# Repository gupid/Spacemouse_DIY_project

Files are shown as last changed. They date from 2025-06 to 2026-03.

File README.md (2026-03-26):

# Spacemouse DIY Project

这是一个开源的 DIY 3D 鼠标 (Spacemouse) 工程。它基于沁恒(WCH)的 CH585 系列微控制器，旨在为 3D 设计、建模和工程人员提供一个高性价比的 3D 控制器解决方案。该设备集成了 3D 鼠标、普通鼠标和键盘功能，并支持有线、蓝牙(BLE)和私有 2.4G RF 连接。

## 硬件概述与驱动

主控为CH585，接收器为CH582F，键盘扫描芯片为CH450，均为沁恒产品。陀螺仪使用MPU9250。

接收器的电路设计借鉴了开源工程[CH582F接收器 - 立创开源硬件平台](https://oshwhub.com/bakacai/ch582f-jie-shou-qi)

主板和键盘PCB为自己设计。

驱动版本：[3Dconnexion 10.7.1](https://3dconnexion.com/cn/driver-download/)

## 主要功能

* **六轴自由度控制**: 使用 MPU9250 传感器，实现平移、旋转、缩放等直观的 3D 空间操作。
* **多模式切换**: 支持USB、BLE、2.4GHz三种模式连接
* **可编程按键**: 可在USB/2.4GHz模式下通过上位机自由修改。

## 演示视频

**[点击播放演示视频](./docs/media/spacemouse-demo.mp4)**

仅展示了外观与核心功能

## 工程文件结构

* **`Spacemouse_develop/`**: 这是 3D 鼠标设备本身的主体固件。
  * `APP/`: 应用层代码，包括主逻辑 `main.c` 和模式管理 `mode_manager.c` 等。
  * `Driver/`: 驱动程序，用于控制 MPU9250 传感器、CH450 按键芯片和 WS2812B RGB LED。
  * `Middleware/`: 中间件代码，处理运动数据、HID 报告和无线通信。
  * `HAL/`, `LIB/`, `StdPeriphDriver/`: 硬件抽象层、库文件和沁恒官方提供的标准外设驱动。
* **`spacemouse_RF_To_USB/`**: 这是CH585版本的 2.4G RF 无线接收器（USB Dongle）的固件。
  * `src/`: 接收器的主逻辑，负责接收 2.4G 信号并将其转换为 USB HID 数据。
  * `HAL/`, `LIB/`, `StdPeriphDriver/`: 与设备端类似的底层驱动和库。
* **`spacemouse_RF_To_USB_CH582/`**: 这是CH582版本的 2.4G RF 无线接收器（USB Dongle）的固件。
* `上位机`：这是和设备配套使用的，可以通过此HTML文件自由配置键值和转轴灵敏度。

## 写在最后

此工程为2025年嵌入式芯片与系统设计竞赛应用赛道——沁恒赛道的作品。实际上，到本次大赛结束时，我们的作品依然没有做完。这份决赛的代码，目前实现的功能有：USB模式、2.4GHz模式、上位机配置、比较稳定的陀螺仪控制。而仍然有待提升的有BLE模式，BLE模式极其不稳定，键盘和摇杆都有很大问题。

同时主板PCB设计也存在一定问题，锂电池的充电功能可行，但供电时却电压不足。

这个作品仍未走到它的结局，而我们和它和比赛的缘分却已走到尽头。

如果有缘，或许未来还会继续优化，我能感到，自己心中还有很多idea在熊熊燃烧。也欢迎所有朋友，如果你也对此感兴趣，希望这份工程能帮到你。

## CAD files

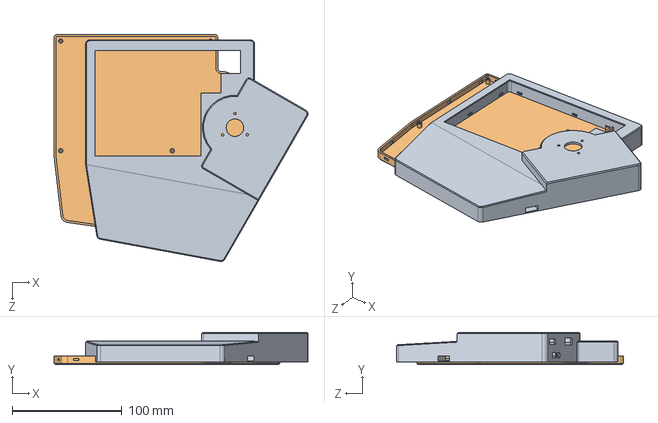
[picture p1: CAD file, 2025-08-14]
model/键盘壳V5.SLDASM
231.9 x 29.5 x 207.3 mm
键盘壳-底部V5
键盘壳-顶部V5

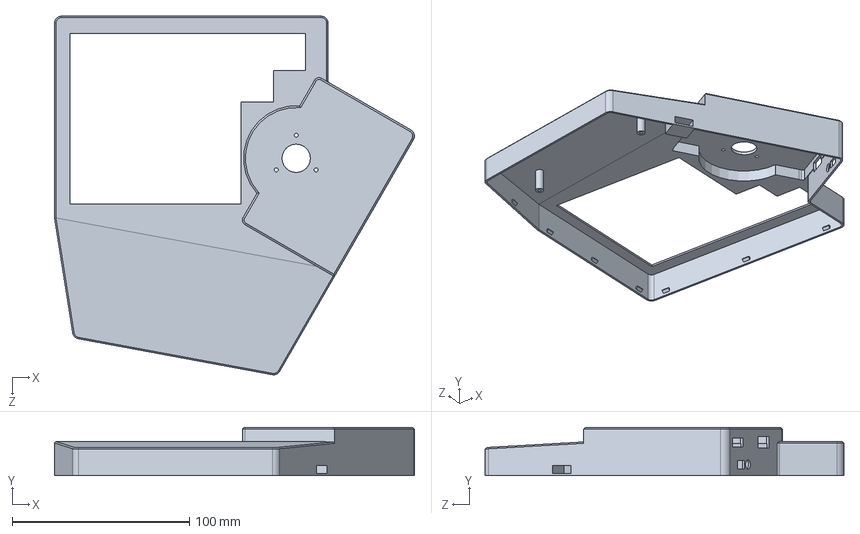
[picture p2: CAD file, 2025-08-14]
model/键盘壳-顶部V5.SLDPRT
203.1 x 27.2 x 202.4 mm

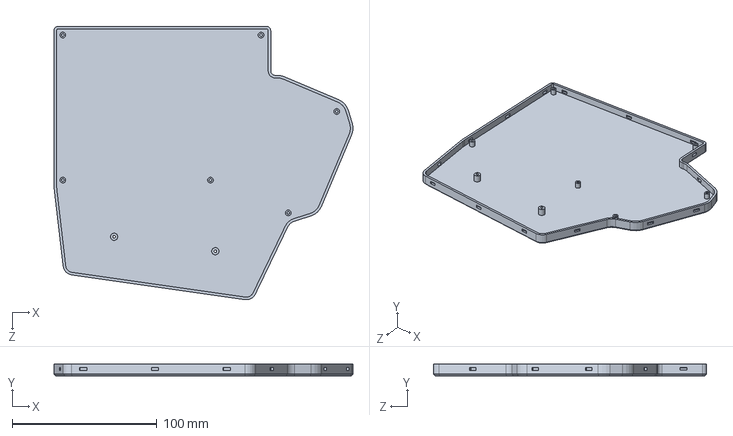
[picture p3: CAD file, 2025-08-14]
model/键盘壳-底部V5.SLDPRT
206.4 x 8.00 x 188.7 mm

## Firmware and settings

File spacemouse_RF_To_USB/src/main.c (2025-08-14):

// 文件名: main.c (环形缓冲区最终方案 - 完整无省略)
// 描述: 使用环形缓冲区(FIFO队列)彻底解决高速、连续数据包丢失问题。

#include "CONFIG.h"
#include "HAL.h"
#include "rf_middleware.h"
#include "usb_hid_composite.h"

// --- USB发送状态机定义 ---
typedef enum {
    USB_SEND_IDLE,
    USB_SEND_KB,
    USB_SEND_SPACEMOUSE_ROT,
    USB_SEND_SPACEMOUSE_TRANS,
    USB_SEND_SPACEMOUSE_ZERO_ROT,
    USB_SEND_SPACEMOUSE_ZERO_TRANS
} usb_send_state_t;

// --- 数据包结构体定义 ---
#define MAX_PACKET_LEN 12
typedef struct {
    uint8_t data[MAX_PACKET_LEN];
    uint8_t length;
} rf_packet_t;


// --- RF数据环形缓冲区 (FIFO队列) ---
#define RF_QUEUE_SIZE 8 // 可缓存8个数据包，足以应对高速按键操作
static volatile rf_packet_t g_rf_queue[RF_QUEUE_SIZE];
static volatile uint8_t g_rf_queue_head = 0; // 消费者(主循环)从此位置读取
static volatile uint8_t g_rf_queue_tail = 0; // 生产者(RF回调)向此位置写入

// --- 全局变量 ---
static volatile usb_send_state_t g_usb_send_state = USB_SEND_IDLE;
__attribute__((aligned(4))) static int16_t g_trans_vals[3];
__attribute__((aligned(4))) static int16_t g_rot_vals[3];
__attribute__((aligned(4))) static uint8_t g_usb_report_buffer[8];

// --- CDC (虚拟串口) 相关全局变量 ---
#define CDC_RX_BUF_SIZE 64
uint8_t g_cdc_rx_buf[CDC_RX_BUF_SIZE];
volatile uint8_t g_cdc_rx_len = 0;
volatile bool g_cdc_data_received_flag = false;

// --- RF 配置 ---
#define RF_ACCESS_ADDRESS   0x4B65794D
#define RF_CHANNEL          40

// --- 函数声明 ---
void OnDataReceived_RF(const uint8_t *data, uint8_t length, int8_t rssi);

__attribute__((aligned(4))) uint32_t MEM_BUF[BLE_MEMHEAP_SIZE / 4];


/*********************************************************************
 * @fn      main
 *
 * @brief   接收器主函数
 *
 * @return  none
 */
int main(void)
{
    // --- 1. 系统初始化 ---
#if(defined(DCDC_ENABLE)) && (DCDC_ENABLE == TRUE)
    PWR_DCDCCfg(ENABLE);
#endif
    HSECFG_Capacitance(HSECap_18p);
    SetSysClock(CLK_SOURCE_HSE_PLL_62_4MHz);
    CH58x_BLEInit();
    HAL_Init();
    GPIOA_SetBits(GPIO_Pin_9);
    GPIOA_ModeCfg(GPIO_Pin_8, GPIO_ModeIN_PU);
    GPIOA_ModeCfg(GPIO_Pin_9, GPIO_ModeOut_PP_5mA);
    UART1_DefInit();

    // --- 2. USB HID复合设备初始化 ---
    usb_hid_composite_init();
    PRINT("USB HID Composite Dongle Initialized.\n");
    RF_RoleInit();
    
    // --- 3. 2.4G RF模块初始化 ---
    RF_MW_Init(OnDataReceived_RF);
    PRINT("Receiver Initialized with Ring Buffer.\n");
    
    // --- 4. 进入主循环 ---
    while(1)
    {
        // 4.1 核心：始终运行TMOS，处理底层RF事件
        TMOS_SystemProcess();

        // 4.2 检查队列是否为空，以及USB是否空闲，以启动新的发送任务
        if ((g_rf_queue_head != g_rf_queue_tail) && (g_usb_send_state == USB_SEND_IDLE)) {
            
            // 从队列头部取出一个数据包 (出队操作)
            rf_packet_t current_packet = g_rf_queue[g_rf_queue_head];
            g_rf_queue_head = (g_rf_queue_head + 1) % RF_QUEUE_SIZE;

            // 根据取出的数据包，设置USB状态机
            if (current_packet.length == 8) {
                memcpy(g_usb_report_buffer, current_packet.data, 8);
                g_usb_send_state = USB_SEND_KB;
            } else if (current_packet.length == 12) {
                memcpy(g_trans_vals, current_packet.data, 6);
                memcpy(g_rot_vals, current_packet.data + 6, 6);
                
                if (g_rot_vals[0] != 0 || g_rot_vals[1] != 0 || g_rot_vals[2] != 0) {
                    g_usb_send_state = USB_SEND_SPACEMOUSE_ROT;
                } else if (g_trans_vals[0] != 0 || g_trans_vals[1] != 0 || g_trans_vals[2] != 0) {
                    g_usb_send_state = USB_SEND_SPACEMOUSE_TRANS;
                } else {
                    g_usb_send_state = USB_SEND_SPACEMOUSE_ZERO_TRANS;
                }
            }
        }
        
        // 4.3 状态机：执行USB发送任务
        switch (g_usb_send_state)
        {
            case USB_SEND_KB:
                if (usb_hid_is_ep1_ready()) { 
                    usb_hid_send_report(g_usb_report_buffer);
                    g_usb_send_state = USB_SEND_IDLE;
                }
                break;

            case USB_SEND_SPACEMOUSE_ROT:
                if (usb_hid_is_ep2_ready()) { 
                    usb_hid_send_spacemouse_report(0x02, g_rot_vals);
                    g_usb_send_state = USB_SEND_SPACEMOUSE_ZERO_TRANS;
                }
                break;

            case USB_SEND_SPACEMOUSE_TRANS:
                if (usb_hid_is_ep2_ready()) {
                    usb_hid_send_spacemouse_report(0x01, g_trans_vals);
                    g_usb_send_state = USB_SEND_SPACEMOUSE_ZERO_ROT;
                }
                break;

            case USB_SEND_SPACEMOUSE_ZERO_ROT:
                 if (usb_hid_is_ep2_ready()) {
                    usb_hid_send_spacemouse_report(0x02, NULL);
                    g_usb_send_state = USB_SEND_IDLE;
                }
                break;
            
            case USB_SEND_SPACEMOUSE_ZERO_TRANS:
                if (usb_hid_is_ep2_ready()) {
                    usb_hid_send_spacemouse_report(0x01, NULL);
                    g_usb_send_state = USB_SEND_SPACEMOUSE_ZERO_ROT;
                }
                break;
                
            case USB_SEND_IDLE:
            default:
                // 空闲状态，等待新任务
                break;
        }

        // 4.4 处理从USB CDC收到的数据 
        if (g_cdc_data_received_flag) {
            RF_MW_SendData(g_cdc_rx_buf, g_cdc_rx_len);
            g_cdc_data_received_flag = false;
        }
    }
}


/*********************************************************************
 * @fn      OnDataReceived_RF
 *
 * @brief   RF数据接收回调函数 (修改为向环形缓冲区入队)
 *
 * @return  none
 */
void OnDataReceived_RF(const uint8_t *data, uint8_t length, int8_t rssi)
{
    // 计算下一个尾部指针的位置
    uint8_t next_tail = (g_rf_queue_tail + 1) % RF_QUEUE_SIZE;

    // 检查队列是否已满 (下一个尾部指针追上头部指针)
    if (next_tail == g_rf_queue_head) {
        // 队列已满，丢弃当前数据包。
        // 这种情况在正常使用中几乎不会发生，除非USB长时间阻塞。
        return; 
    }

    // 验证数据长度是否为有效载荷
    if ((length == 8 || length == 12) && data != NULL)
    {
        // 将数据包存入队列尾部 (入队操作)
        g_rf_queue[g_rf_queue_tail].length = length;
        memcpy((void*)g_rf_queue[g_rf_queue_tail].data, data, length);
        
        // 移动尾部指针，完成入队
        g_rf_queue_tail = next_tail;
    }
}

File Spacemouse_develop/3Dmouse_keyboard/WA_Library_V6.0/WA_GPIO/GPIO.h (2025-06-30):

#ifndef __GPIO_H
#define __GPIO_H

#include "main.h"


// 定义一个函数指针指向GPIOA,GPIOB的端口引脚模式配置函数
typedef void(*GPIO_MODE_Cfg) (uint32_t, GPIOModeTypeDef);

// 定义一个评估板GPIO的结构体存放GPIO的引脚和端口引脚模式配置函数
typedef struct GPIO_HandleDef{
    uint8_t gpio;
    uint32_t gpio_pin;
    uint8_t gpio_mode;
    GPIO_MODE_Cfg GPIOMODECfg;
    uint8_t gpioit;               //触发中断的标志
}GPIO_HandleDef;

extern GPIO_HandleDef waGPIOA;
extern GPIO_HandleDef waGPIOB;

//宏定义两个组别A,B，因为CH585只有两组引脚
#define GPIOA 'A'
#define GPIOB 'B'

//定义推挽输出初始化默认的上下拉状态
#define GPIO_PIN_SET 1
#define GPIO_PIN_RESET 0
#define GPIO_PIN_NULL 2

//GPIO初始化函数
void WA_GPIO_Init(GPIO_HandleDef *defgpio,uint32_t gpiopin,uint8_t gpiomode,uint8_t output);
//GPIO外部中断初始化函数
void WA_GPIO_IT_Init(GPIO_HandleDef *defgpio,uint32_t gpiopin,uint8_t gpioedg);

//“厨子函数”：对“配置清单”进行处理
void WA_GPIO_MspInit(GPIO_HandleDef *defgpio,uint8_t output);
//“厨子函数”：对“配置清单”进行处理
void WA_GPIO_IT_MspInit(GPIO_HandleDef *defgpio);

//回调函数
void WA_GPIOA_EventCallBack(uint32_t gpiopin);
void WA_GPIOB_EventCallBack(uint32_t gpiopin);

#endif

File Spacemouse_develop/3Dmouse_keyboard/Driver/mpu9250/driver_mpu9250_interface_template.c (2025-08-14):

/**
 * Copyright (c) 2015 - present LibDriver All rights reserved
 * 
 * The MIT License (MIT)
 *
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
 * @file      driver_mpu9250_interface_template.c
 * @brief     driver mpu9250 interface template source file
 * @version   1.0.0
 * @author    Shifeng Li
 * @date      2022-08-30
 *
 * <h3>history</h3>
 * <table>
 * <tr><th>Date        <th>Version  <th>Author      <th>Description
 * <tr><td>2022/08/30  <td>1.0      <td>Shifeng Li  <td>first upload
 * </table>
 */

#include "driver_mpu9250_interface.h"
#include "main.h"
/**
 * @brief  interface iic bus init
 * @return status code
 *         - 0 success
 *         - 1 iic init failed
 * @note   none
 */
uint8_t mpu9250_interface_iic_init(void)
{
    WA_I2C_Init(&wai2c0,GPIOB,GPIO_Pin_4,GPIOB,GPIO_Pin_5,1);
    return 0;
}

/**
 * @brief  interface iic bus deinit
 * @return status code
 *         - 0 success
 *         - 1 iic deinit failed
 * @note   none
 */
uint8_t mpu9250_interface_iic_deinit(void)
{
    return 0;
}

/**
 * @brief      interface iic bus read
 * @param[in]  addr iic device write address
 * @param[in]  reg iic register address
 * @param[out] *buf pointer to a data buffer
 * @param[in]  len length of the data buffer
 * @return     status code
 * - 0 success
 * - 1 read failed
 * @note       none
 */
uint8_t mpu9250_interface_iic_read(uint8_t addr, uint8_t reg, uint8_t *buf, uint16_t len)
{
     // 将驱动传入的8位地址(如0xD0)右移一位，得到7位地址(0x68)
    uint8_t dev_addr_7bit = addr >> 1;

    // 调用底层库，传入正确的7位地址
    if (WA_Read_Len(&wai2c0, dev_addr_7bit, reg, (uint8_t)len, buf) == 0)
    {
        return 0; // 成功
    }
    else
    {
        return 1; // 失败
    }
}

/**
 * @brief      (新版) 接口I2C读函数 - 7位地址版本
 * @param[in]  addr iic 设备的7位地址 (例如 0x68)
 * @param[in]  reg iic 寄存器地址
 * @param[out] *buf 指向数据缓冲区的指针
 * @param[in]  len 数据缓冲区的长度
 * @return     状态码
 * - 0 成功
 * - 1 读取失败
 * @note       此版本直接使用传入的7位地址，不进行转换。
 */
uint8_t mpu9250_interface_iic_read_7bit_addr(uint8_t addr, uint8_t reg, uint8_t *buf, uint16_t len)
{
    // 直接调用底层库，传入未修改的7位地址
    if (WA_Read_Len(&wai2c0, addr, reg, (uint8_t)len, buf) == 0)
    {
        return 0; // 成功
    }
    else
    {
        return 1; // 失败
    }
}

/**
 * @brief     (新版) 接口I2C写函数 - 7位地址版本
 * @param[in] addr iic 设备的7位地址 (例如 0x68)
 * @param[in] reg iic 寄存器地址
 * @param[in] *buf 指向数据缓冲区的指针
 * @param[in] len 数据缓冲区的长度
 * @return    状态码
 * - 0 成功
 * - 1 写入失败
 * @note      此版本直接使用传入的7位地址，不进行转换。
 */
uint8_t mpu9250_interface_iic_write_7bit_addr(uint8_t addr, uint8_t reg, uint8_t *buf, uint16_t len)
{
    // 直接调用底层库，传入未修改的7位地址
    if (WA_Write_Len(&wai2c0, addr, reg, (uint8_t)len, buf) == 0)
    {
        return 0; // 成功
    }
    else
    {
        return 1; // 失败
    }
}

/**
 * @brief      interface iic bus write
 * @param[in]  addr iic device write address
 * @param[in]  reg iic register address
 * @param[in]  *buf pointer to a data buffer
 * @param[in]  len length of the data buffer
 * @return     status code
 * - 0 success
 * - 1 write failed
 * @note       none
 */
uint8_t mpu9250_interface_iic_write(uint8_t addr, uint8_t reg, uint8_t *buf, uint16_t len)
{
    // 将驱动传入的8位地址(如0xD0)右移一位，得到7位地址(0x68)
    uint8_t dev_addr_7bit = addr >> 1;

    // 调用底层库，传入正确的7位地址
    if (WA_Write_Len(&wai2c0, dev_addr_7bit, reg, (uint8_t)len, buf) == 0)
    {
        return 0; // 成功
    }
    else
    {
        return 1; // 失败
    }
}

/**
 * @brief  interface spi bus init
 * @return status code
 *         - 0 success
 *         - 1 spi init failed
 * @note   none
 */
uint8_t mpu9250_interface_spi_init(void)
{
    WA_SPI0_Hardware_Init(Master,Pin_Disable);
    return 0;
}

/**
 * @brief  interface spi bus deinit
 * @return status code
 *         - 0 success
 *         - 1 spi deinit failed
 * @note   none
 */
uint8_t mpu9250_interface_spi_deinit(void)
{   
    R8_SPI0_CTRL_MOD = RB_SPI_ALL_CLEAR;
    R8_SPI0_CTRL_CFG &= ~(RB_SPI_AUTO_IF | RB_SPI_DMA_ENABLE);
    return 0;
}

/**
 * @brief      interface spi bus read
 * @param[in]  reg register address
 * @param[out] *buf pointer to a data buffer
 * @param[in]  len length of data buffer
 * @return     status code
 *             - 0 success
 *             - 1 read failed
 * @note       none
 */
uint8_t mpu9250_interface_spi_read(uint8_t reg, uint8_t *buf, uint16_t len)
{
     // 准备要发送的读命令字节 (寄存器地址的最高位置1)
    uint8_t read_cmd = reg | 0x80;
    SPI0_CSS_L(); 
    SPI0_MasterSendByte(read_cmd);
    SPI0_MasterRecv(buf, len);
    SPI0_CSS_H(); 

    return 0; 
}

/**
 * @brief     interface spi bus write
 * @param[in] reg register address
 * @param[in] *buf pointer to a data buffer
 * @param[in] len length of data buffer
 * @return    status code
 *            - 0 success
 *            - 1 write failed
 * @note      none
 */
uint8_t mpu9250_interface_spi_write(uint8_t reg, uint8_t *buf, uint16_t len)
{
    uint8_t write_cmd = reg & 0x7F;
    SPI0_CSS_L(); 
    SPI0_MasterSendByte(write_cmd);
    SPI0_MasterTrans(buf,len);
    SPI0_CSS_H(); 

    return 0; 
}

/**
 * @brief     interface delay ms
 * @param[in] ms time
 * @note      none
 */
void mpu9250_interface_delay_ms(uint32_t ms)
{
    DelayMs(ms);
}

/**
 * @brief     interface print format data
 * @param[in] fmt format data
 * @note      none
 */
void mpu9250_interface_debug_print(const char *const fmt, ...)
{
    char str[128];
    va_list args;  
    va_start(args, fmt);
    vsnprintf(str, sizeof(str), fmt, args);
    va_end(args);
    PRINT("%s", str); 
}

/**
 * @brief     interface receive callback
 * @param[in] type irq type
 * @note      none
 */
void mpu9250_interface_receive_callback(uint8_t type)
{
    switch (type)
    {
        case MPU9250_INTERRUPT_MOTION :
        {
            mpu9250_interface_debug_print("mpu9250: irq motion.\n");
            
            break;
        }
        case MPU9250_INTERRUPT_FIFO_OVERFLOW :
        {
            mpu9250_interface_debug_print("mpu9250: irq fifo overflow.\n");
            
            break;
        }
        case MPU9250_INTERRUPT_FSYNC_INT :
        {
            mpu9250_interface_debug_print("mpu9250: irq fsync int.\n");
            
            break;
        }
        case MPU9250_INTERRUPT_DMP :
        {
            mpu9250_interface_debug_print("mpu9250: irq dmp\n");
            
            break;
        }
        case MPU9250_INTERRUPT_DATA_READY :
        {
            mpu9250_interface_debug_print("mpu9250: irq data ready\n");
            
            break;
        }
        default :
        {
            mpu9250_interface_debug_print("mpu9250: irq unknown code.\n");
            
            break;
        }
    }
}
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

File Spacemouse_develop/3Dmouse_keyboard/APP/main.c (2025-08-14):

#include "CONFIG.h"
#include "HAL.h"
#include "hiddev.h"
#include "ble_hid_app.h"
#include "main.h"
#include "usb_hid_composite.h"
#include "motion_engine.h"
#include "mode_manager.h"
#include "keyboard.h"
#include "ws2812b_control.h"

MotionEngine_State mouse_motion;
volatile uint8_t g_ahrs_update_flag = 0;
extern volatile uint8_t g_ws2812b_dma_busy;
/*********************************************************************
 * GLOBAL TYPEDEFS
 */
__attribute__((aligned(4))) uint32_t MEM_BUF[BLE_MEMHEAP_SIZE / 4];

#if(defined(BLE_MAC)) && (BLE_MAC == TRUE)
const uint8_t MacAddr[6] = {0x84, 0xC2, 0xE4, 0x03, 0x02, 0x02};
#endif

/*********************************************************************
 * @fn      WA_TIM_PeriodCallBack
 *
 * @brief   定时器周期中断回调函数 (我们需要重写这个__weak_symbol函数)
 *
 * @param   watime - 定时器句柄
 *
 * @return  none
 */
void WA_TIM_PeriodCallBack(TIM_HandleDef *watime)
{
    // 判断是否是我们用于AHRS的定时器TMR1触发了中断
    if (watime == &watime1)
    {
        // 在中断里只做最简单的事：设置标志位
        g_ahrs_update_flag = 1;
    }
}

/*********************************************************************
 * @fn      Main_Circulation
 *
 * @brief   主循环
 *
 * @return  none
 */
__HIGH_CODE
__attribute__((noinline))
void Main_Circulation()
{
    while(1)
    {
       ModeManager_MainLoop();
       keyboard_LED_display();
    }
}

int main(void)
{
#if(defined(DCDC_ENABLE)) && (DCDC_ENABLE == TRUE)
    PWR_DCDCCfg(ENABLE);
#endif
    HSECFG_Capacitance(HSECap_18p);
    SetSysClock(CLK_SOURCE_HSE_PLL_62_4MHz);
#if(defined(HAL_SLEEP)) && (HAL_SLEEP == TRUE)
    GPIOA_ModeCfg(GPIO_Pin_All, GPIO_ModeIN_PU);
    GPIOB_ModeCfg(GPIO_Pin_All, GPIO_ModeIN_PU);
#endif
#ifdef DEBUG
    WA_UART_Init(&wauart1,115200);
#endif
    WA_TIM_IT_Init(&watime1, WA_TIMER, Pin_Disable, 50, null, null);
    //键盘0，USB1，定时器（鼠标）2
    PFIC_SetPriority(TMR1_IRQn,2);
    PFIC_DisableIRQ(TMR1_IRQn);
    Keyboard_Init();
    WS2812B_Init();
    ModeManager_Init();
    MotionEngine_Init(&mouse_motion);
    Main_Circulation(); // 进入主循环
}

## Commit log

2025-05-10 Create 键盘壳
2025-06-30 MPU9250控制鼠标-调试版本
2025-07-09 初赛版 part1
2025-07-09 初赛版 part2
2025-07-09 2.4GHz接收器代码 初赛版
2025-07-09 主板、2.4GHz接收器PCB文件 初赛版
2025-07-09 键盘PCB 初赛版
2025-07-09 被过程淘汰的TLV493D传感器PCB文件
2025-07-09 Create 模型
2025-07-09 Create 键盘模型
2025-08-14 2.4GHz接收器
2025-08-14 删除模型和TLV文件夹
    [Knob.SLDPRT, MPU9250.SLDPRT, 键盘壳V4.SLDASM]
2025-08-14 删除文件夹]
2025-08-14 2.4GHz接收器CH585版本
2025-08-14 决赛版本
2025-08-14 Create 决赛版
2026-03-15 视频演示
2026-03-26 驱动声明更新
